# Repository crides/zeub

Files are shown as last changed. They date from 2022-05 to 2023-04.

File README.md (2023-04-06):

# Zeub

zeub is meant to be a pixel clock and a IoT hub. The name comes from a smooshed version of zeit (German for time) and hub.

It currently has:
- a 8x8 RGB LED matrix and a 32x8 white LED matrix
- 2 2-channel LED strip controllers (for controlling LED strips with warm and cool white lights in my room)
- a 128x64 OLED screen
- a TMP117 precision temperature sensor
- 2 front facing speakers, using 2 MAX98357 DACs
- a DS3212 battery backed RTC
- a EVQWGD001 rotary encoder, and a 5-way joystick
- a nRF52840 microcontroller, which supports USB, BLE and 802.15.4 (ZigBee etc.) protocols

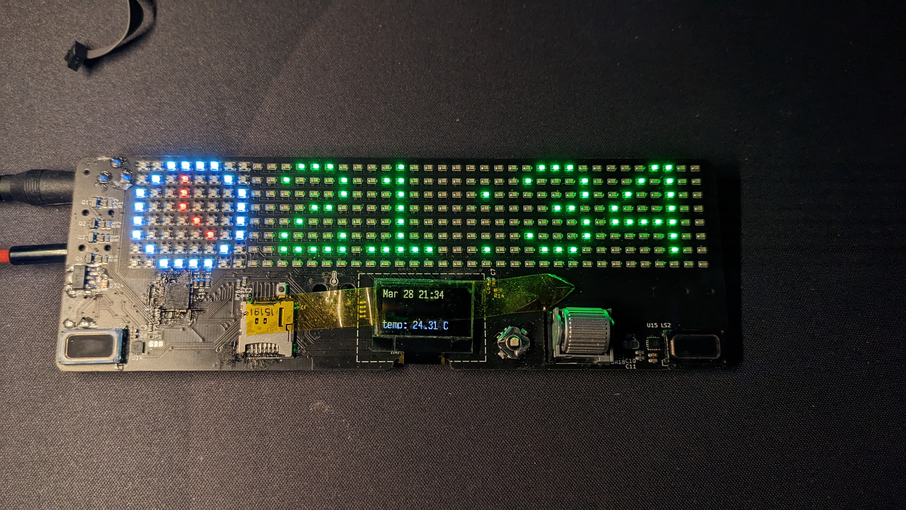
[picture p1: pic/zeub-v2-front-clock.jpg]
Version 2 assembled displaying a clock icon and time (the right side is green because uh.. I messed up the PCBA parts assignment): 

The current firmware fetches the current time (once; supports connection at 2 times for drift correction) from a CTS (Current Time Service) from a BLE connection. This is currently done using my phone through the nRF Connect app. The time is then displayed on both the LED matrix (along with a clock icon), and the OLED along with the date and current temperature. It also sets the brightness of one LED strip using a preconfigured (but can be reconfigured through BLE) schedule. The other LED strip (which is actually my desk light) is controlled by the scroll wheel. It also streams audio from the USB to the speakers, for testing of the audio interface.

The hub part of the project still doesn't really exist yet, as I haven't had time to get to it.

Version 1 has basically the same features, but also included 2 microphones for testing. However the LED matrix did not work properly as I used 2 LED matrix controllers together in the same matrix.

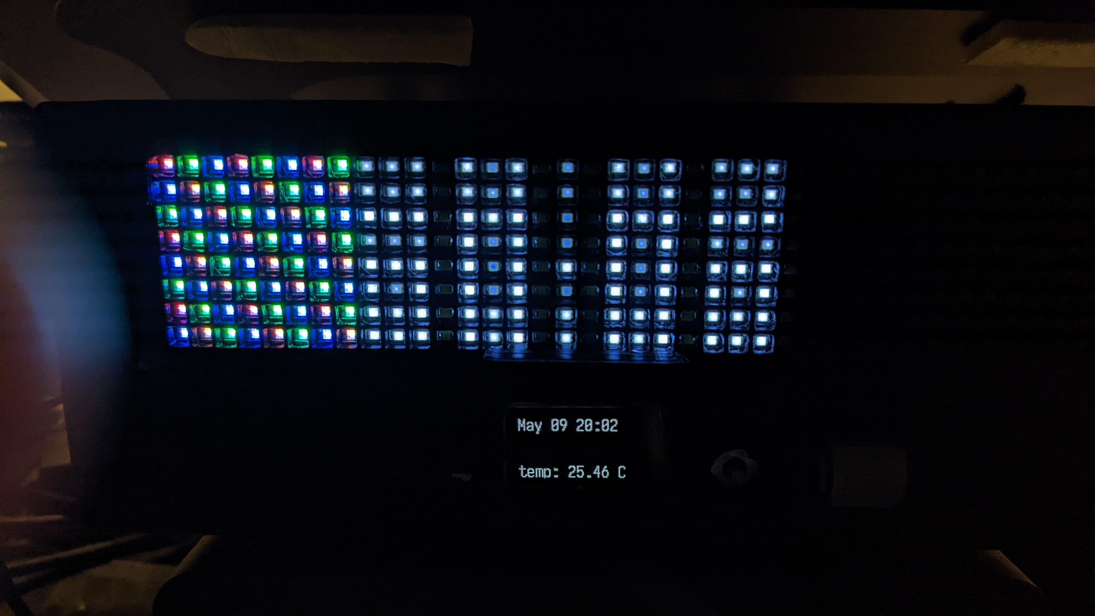
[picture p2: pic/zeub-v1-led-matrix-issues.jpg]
LED matrix issues


The LED strips were also connected through a TRRS cable but without an actual connector, as I flipped the control polarity of the LED strips (they are common anode instead of common cathode).

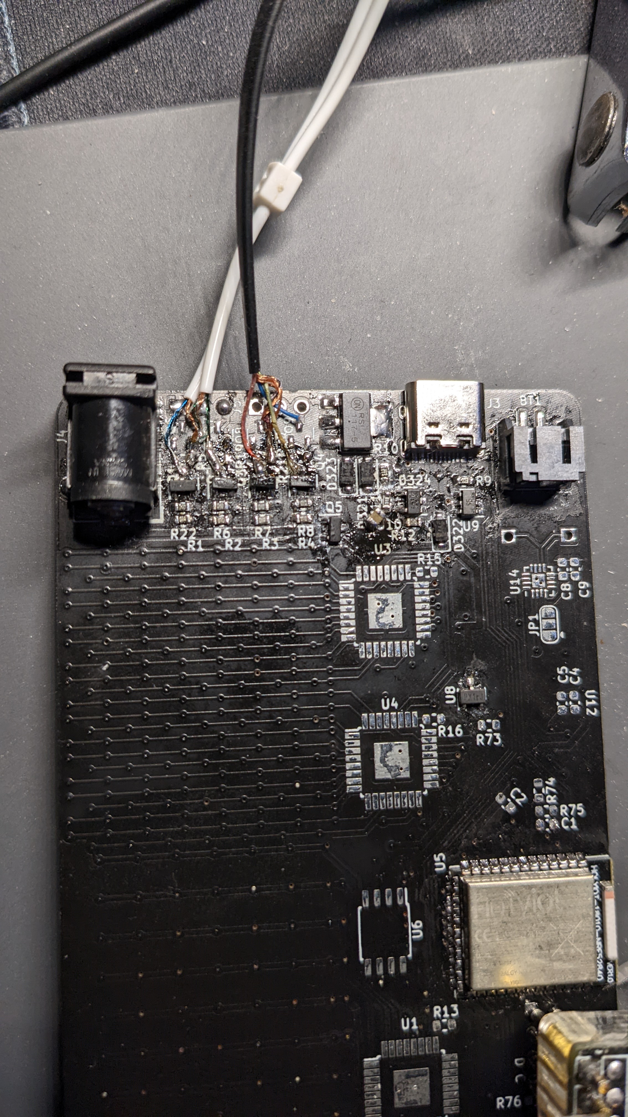
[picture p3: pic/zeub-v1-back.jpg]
V1 backside


Case iterations for v1 (the cone in the back is for better airflow to the temperature sensor, for more accurate reading of the environment):

V1 front cases

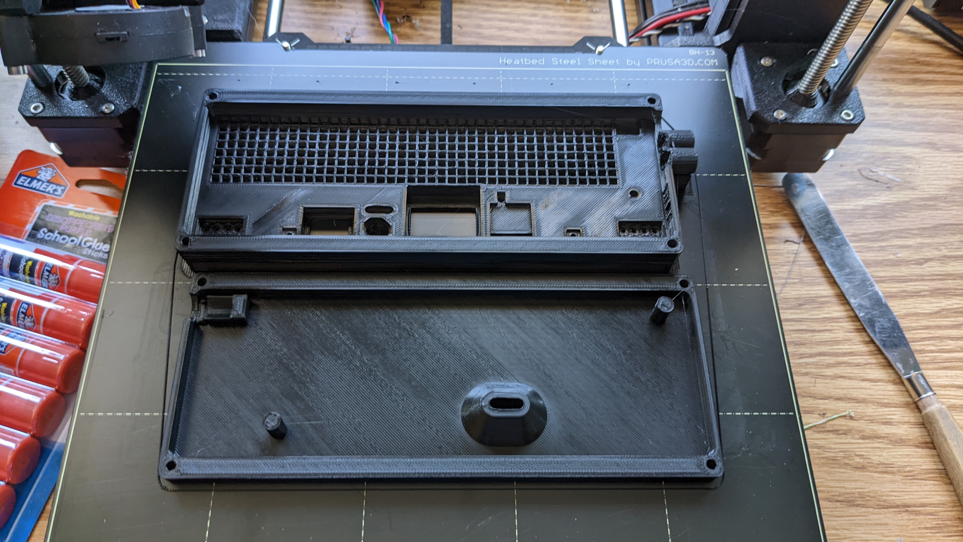
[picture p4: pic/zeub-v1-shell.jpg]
V1 front and back cases


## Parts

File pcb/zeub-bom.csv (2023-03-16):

Comment | Footprint | Designator | LCSC Part #
0.1uF | C_0603_1608Metric | C3,C20,C5,C6,C13,C14,C8,C10
100 | R_0603_1608Metric | R1,R2,R3,R4
100k | R_0603_1608Metric | R5,R6,R7,R8,R22,R73,R74,R75,R17,R18
10k | R_0603_1608Metric | R12,R14,R16
10uF | C_0603_1608Metric | C9,C11
1k | R_0603_1608Metric | R11
1uF | C_0603_1608Metric | C4,C15,C19,C2,C7,C12,C17,C18
2.2k | R_0603_1608Metric | R76,R77
2.2uF | C_0603_1608Metric | C16
390k | R_0603_1608Metric | R13
4.7uF | C_0603_1608Metric | C1
5.1k | R_0603_1608Metric | R9,R10
AO3400A | SOT-23 | Q1,Q2,Q3,Q4,Q5
AudioJack4 | Jack_3.5mm_PJ320D_Horizontal | J2,J5,J6
Barrel_Jack_Switch | BarrelJack_CUI_PJ-102AH_Horizontal | J4
Battery_Cell | JST_PH_S2B-PH-SM4-TB_1x02-1MP_P2.00mm_Horizontal | BT1
DS3231MZ | SOIC-8_3.9x4.9mm_P1.27mm | U3
D_Schottky | D_SOD-123 | D321,D322,D323
IS31FL3741 | QFN-60-1EP_7x7mm_P0.4mm_EP5.4x5.4mm_ThermalVias | U1,U2
LED | D_0805_2012Metric | D324
LED_BGRA | LED_ASMB-KTF0-0A306 | D257,D258,D259,D260,D261,D262,D263,D264,D265,D266,D267,D268,D269,D270,D271,D272,D273,D274,D275,D276,D277,D278,D279,D280,D281,D282,D283,D284,D285,D286,D287,D288,D289,D290,D291,D292,D293,D294,D295,D296,D297,D298,D299,D300,D301,D302,D303,D304,D305,D306,D307,D308,D309,D310,D311,D312,D313,D314,D315,D316,D317,D318,D319,D320
LTC4054ES5-4.2 | TSOT-23-5 | U10
MAX98357A | QFN-16-1EP_3x3mm_P0.5mm_EP1.45x1.45mm | U14,U15
Micro_SD_Card_Det | molex-503182-1852 | J7
OLED-128O064D | OLED-128O064D | DS1
RotaryEncoder_Switch | EVQWGD001 | SW2
SKRHA | SKRHA-boss | SW1
SRV05-4 | SOT-23-6 | U9
SW_Push | SW_SPST_B3U-1000P | SW3
SolderJumper_2_Open | SolderJumper-2_P1.3mm_Open_TrianglePad1.0x1.5mm | JP3,JP4
SolderJumper_3_Open | SolderJumper-3_P1.3mm_Open_RoundedPad1.0x1.5mm | JP1,JP2
Speaker | CMS1609 | LS1,LS2
TLV1117-50 | SOT-223 | U7
TMP117 | WSON-6-1EP_2x2mm_P0.65mm_EP1x1.6mm | U11
USB_C_Receptacle_USB2.0 | USB_C_Receptacle_HRO_TYPE-C-31-M-12 | J3
W25Q128JVS | SOIC-8_5.23x5.23mm_P1.27mm | U6
XC6206PxxxMR | SOT-23-3 | U8
holyiot-18010-no-underside | holyiot-18010-no-underside | U5
jlink | PinHeader_2x05_P1.27mm_Vertical_SMD | J1
white | D_0603_1608Metric | D1,D2,D3,D4,D5,D6,D7,D8,D9,D10,D11,D12,D13,D14,D15,D16,D17,D18,D19,D20,D21,D22,D23,D24,D25,D26,D27,D28,D29,D30,D31,D32,D33,D34,D35,D36,D37,D38,D39,D40,D41,D42,D43,D44,D45,D46,D47,D48,D49,D50,D51,D52,D53,D54,D55,D56,D57,D58,D59,D60,D61,D62,D63,D64,D65,D66,D67,D68,D69,D70,D71,D72,D73,D74,D75,D76,D77,D78,D79,D80,D81,D82,D83,D84,D85,D86,D87,D88,D89,D90,D91,D92,D93,D94,D95,D96,D97,D98,D99,D100,D101,D102,D103,D104,D105,D106,D107,D108,D109,D110,D111,D112,D113,D114,D115,D116,D117,D118,D119,D120,D121,D122,D123,D124,D125,D126,D127,D128,D129,D130,D131,D132,D133,D134,D135,D136,D137,D138,D139,D140,D141,D142,D143,D144,D145,D146,D147,D148,D149,D150,D151,D152,D153,D154,D155,D156,D157,D158,D159,D160,D161,D162,D163,D164,D165,D166,D167,D168,D169,D170,D171,D172,D173,D174,D175,D176,D177,D178,D179,D180,D181,D182,D183,D184,D185,D186,D187,D188,D189,D190,D191,D192,D193,D194,D195,D196,D197,D198,D199,D200,D201,D202,D203,D204,D205,D206,D207,D208,D209,D210,D211,D212,D213,D214,D215,D216,D217,D218,D219,D220,D221,D222,D223,D224,D225,D226,D227,D228,D229,D230,D231,D232,D233,D234,D235,D236,D237,D238,D239,D240,D241,D242,D243,D244,D245,D246,D247,D248,D249,D250,D251,D252,D253,D254,D255,D256

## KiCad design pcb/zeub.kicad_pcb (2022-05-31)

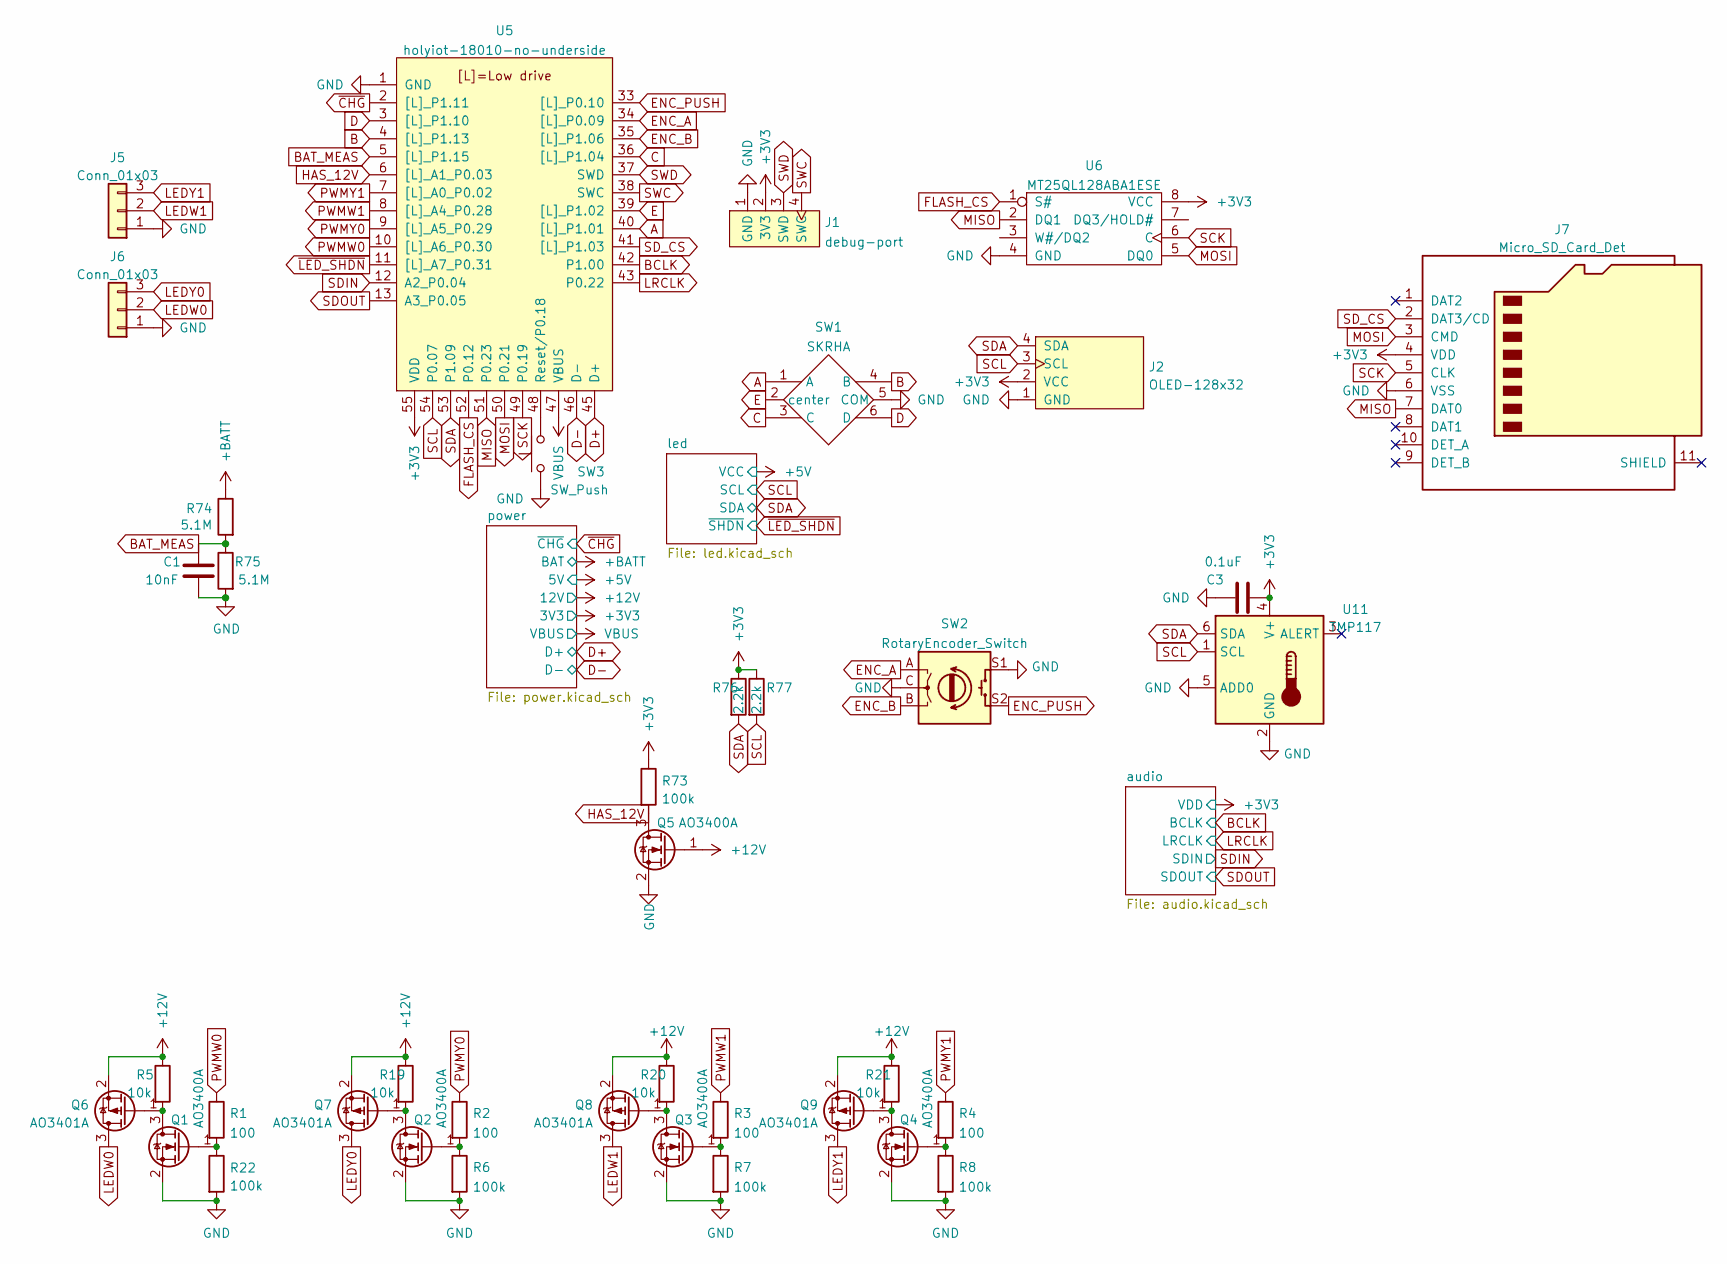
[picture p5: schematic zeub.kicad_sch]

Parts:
C1: 10nF; C_0603_1608Metric
C3: 0.1uF; C_0603_1608Metric
J1: debug-port; debug-port-single-side
J2: OLED-128x32; OLED-128x64
J5, J6: Conn_01x03; PinHeader_1x03_P2.54mm_Vertical
J7: Micro_SD_Card_Det; molex-503182-1852
Q1, Q2, Q3, Q4, Q5: AO3400A; SOT-23
Q6, Q7, Q8, Q9: AO3401A; SOT-23
R1, R2, R3, R4: 100; R_0603_1608Metric
R5, R19, R20, R21: 10k; R_0603_1608Metric
R6, R7, R8, R22, R73: 100k; R_0603_1608Metric
R74, R75: 5.1M; R_0603_1608Metric
R76, R77: 2.2k; R_0603_1608Metric
SW1: SKRHA; SKRHA-boss
SW2: RotaryEncoder_Switch; EVQWGD001
SW3: SW_Push; SW_SPST_B3U-1000P
U5: holyiot-18010-no-underside
U6: MT25QL128ABA1ESE; SOIC-8_5.23x5.23mm_P1.27mm
U11: TMP117; WSON-6-1EP_2x2mm_P0.65mm_EP1x1.6mm

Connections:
+3V3: C3.2, J1.2 (3V3), J2.2 (VCC), J7.4 (VDD), R73.1, R76.1, R77.1, U5.55 (VDD), U6.8 (VCC), U11.4 (V+); also elsewhere on the board
+12V: Q5.1 (G), Q6.2 (S), Q7.2 (S), Q8.2 (S), Q9.2 (S), R5.1, R19.1, R20.1, R21.1; also elsewhere on the board
+BATT: R74.1; also elsewhere on the board
A: SW1.1 (A), U5.40 ([L]_P1.01)
B: SW1.4 (B), U5.4 ([L]_P1.13)
BAT_MEAS: C1.1, R74.2, R75.1, U5.5 ([L]_P1.15)
BCLK: U5.42 (P1.00); also elsewhere on the board
C: SW1.3 (C), U5.36 ([L]_P1.04)
D: SW1.6 (D), U5.3 ([L]_P1.10)
D+: U5.45 (D+); also elsewhere on the board
D-: U5.46 (D-); also elsewhere on the board
E: SW1.2 (center), U5.39 ([L]_P1.02)
ENC_A: SW2.A, U5.34 ([L]_P0.09)
ENC_B: SW2.B, U5.35 ([L]_P1.06)
ENC_PUSH: SW2.S2, U5.33 ([L]_P0.10)
FLASH_CS: U5.52 (P0.12), U6.1 (S#)
GND: C1.2, C3.1, J1.1 (GND), J2.1 (GND), J5.1, J6.1, J7.6 (VSS), Q1.2 (S), Q2.2 (S), Q3.2 (S), Q4.2 (S), Q5.2 (S), R6.2, R7.2, R8.2, R22.2, R75.2, SW1.5 (COM), SW2.C, SW2.S1, SW3.1, U5.1 (GND), U5.32 (GND), U5.44 (GND), U6.4 (GND), U11.2 (GND), U11.5 (ADD0), U11.7 (GND); also elsewhere on the board
HAS_12V: Q5.3 (D), R73.2, U5.6 ([L]_A1_P0.03)
LEDW0: J6.2, Q6.3 (D)
LEDW1: J5.2, Q8.3 (D)
LEDY0: J6.3, Q7.3 (D)
LEDY1: J5.3, Q9.3 (D)
LRCLK: U5.43 (P0.22); also elsewhere on the board
MISO: J7.7 (DAT0), U5.51 (P0.23), U6.2 (DQ1)
MOSI: J7.3 (CMD), U5.50 (P0.21), U6.5 (DQ0)
unnamed: Q1.1 (G), R1.2, R22.1
unnamed: Q1.3 (D), Q6.1 (G), R5.2
unnamed: Q2.1 (G), R2.2, R6.1
unnamed: Q2.3 (D), Q7.1 (G), R19.2
unnamed: Q3.1 (G), R3.2, R7.1
unnamed: Q3.3 (D), Q8.1 (G), R20.2
unnamed: Q4.1 (G), R4.2, R8.1
unnamed: Q4.3 (D), Q9.1 (G), R21.2
unnamed: SW3.2, U5.48 (Reset/P0.18)
PWMW0: R1.1, U5.10 ([L]_A6_P0.30)
PWMW1: R3.1, U5.8 ([L]_A4_P0.28)
PWMY0: R2.1, U5.9 ([L]_A5_P0.29)
PWMY1: R4.1, U5.7 ([L]_A0_P0.02)
SCK: J7.5 (CLK), U5.49 (P0.19), U6.6 (C)
SCL: J2.3 (SCL), R77.2, U5.54 (P0.07), U11.1 (SCL); also elsewhere on the board
SDA: J2.4 (SDA), R76.2, U5.53 (P1.09), U11.6 (SDA); also elsewhere on the board
SDIN: U5.12 (A2_P0.04); also elsewhere on the board
SDOUT: U5.13 (A3_P0.05); also elsewhere on the board
SD_CS: J7.2 (DAT3/CD), U5.41 ([L]_P1.03)
SWC: J1.4 (SWC), U5.38 (SWC)
SWD: J1.3 (SWD), U5.37 (SWD)
VBUS: U5.47 (VBUS); also elsewhere on the board
~CHG: U5.2 ([L]_P1.11); also elsewhere on the board
~LED_SHDN: U5.11 ([L]_A7_P0.31); also elsewhere on the board

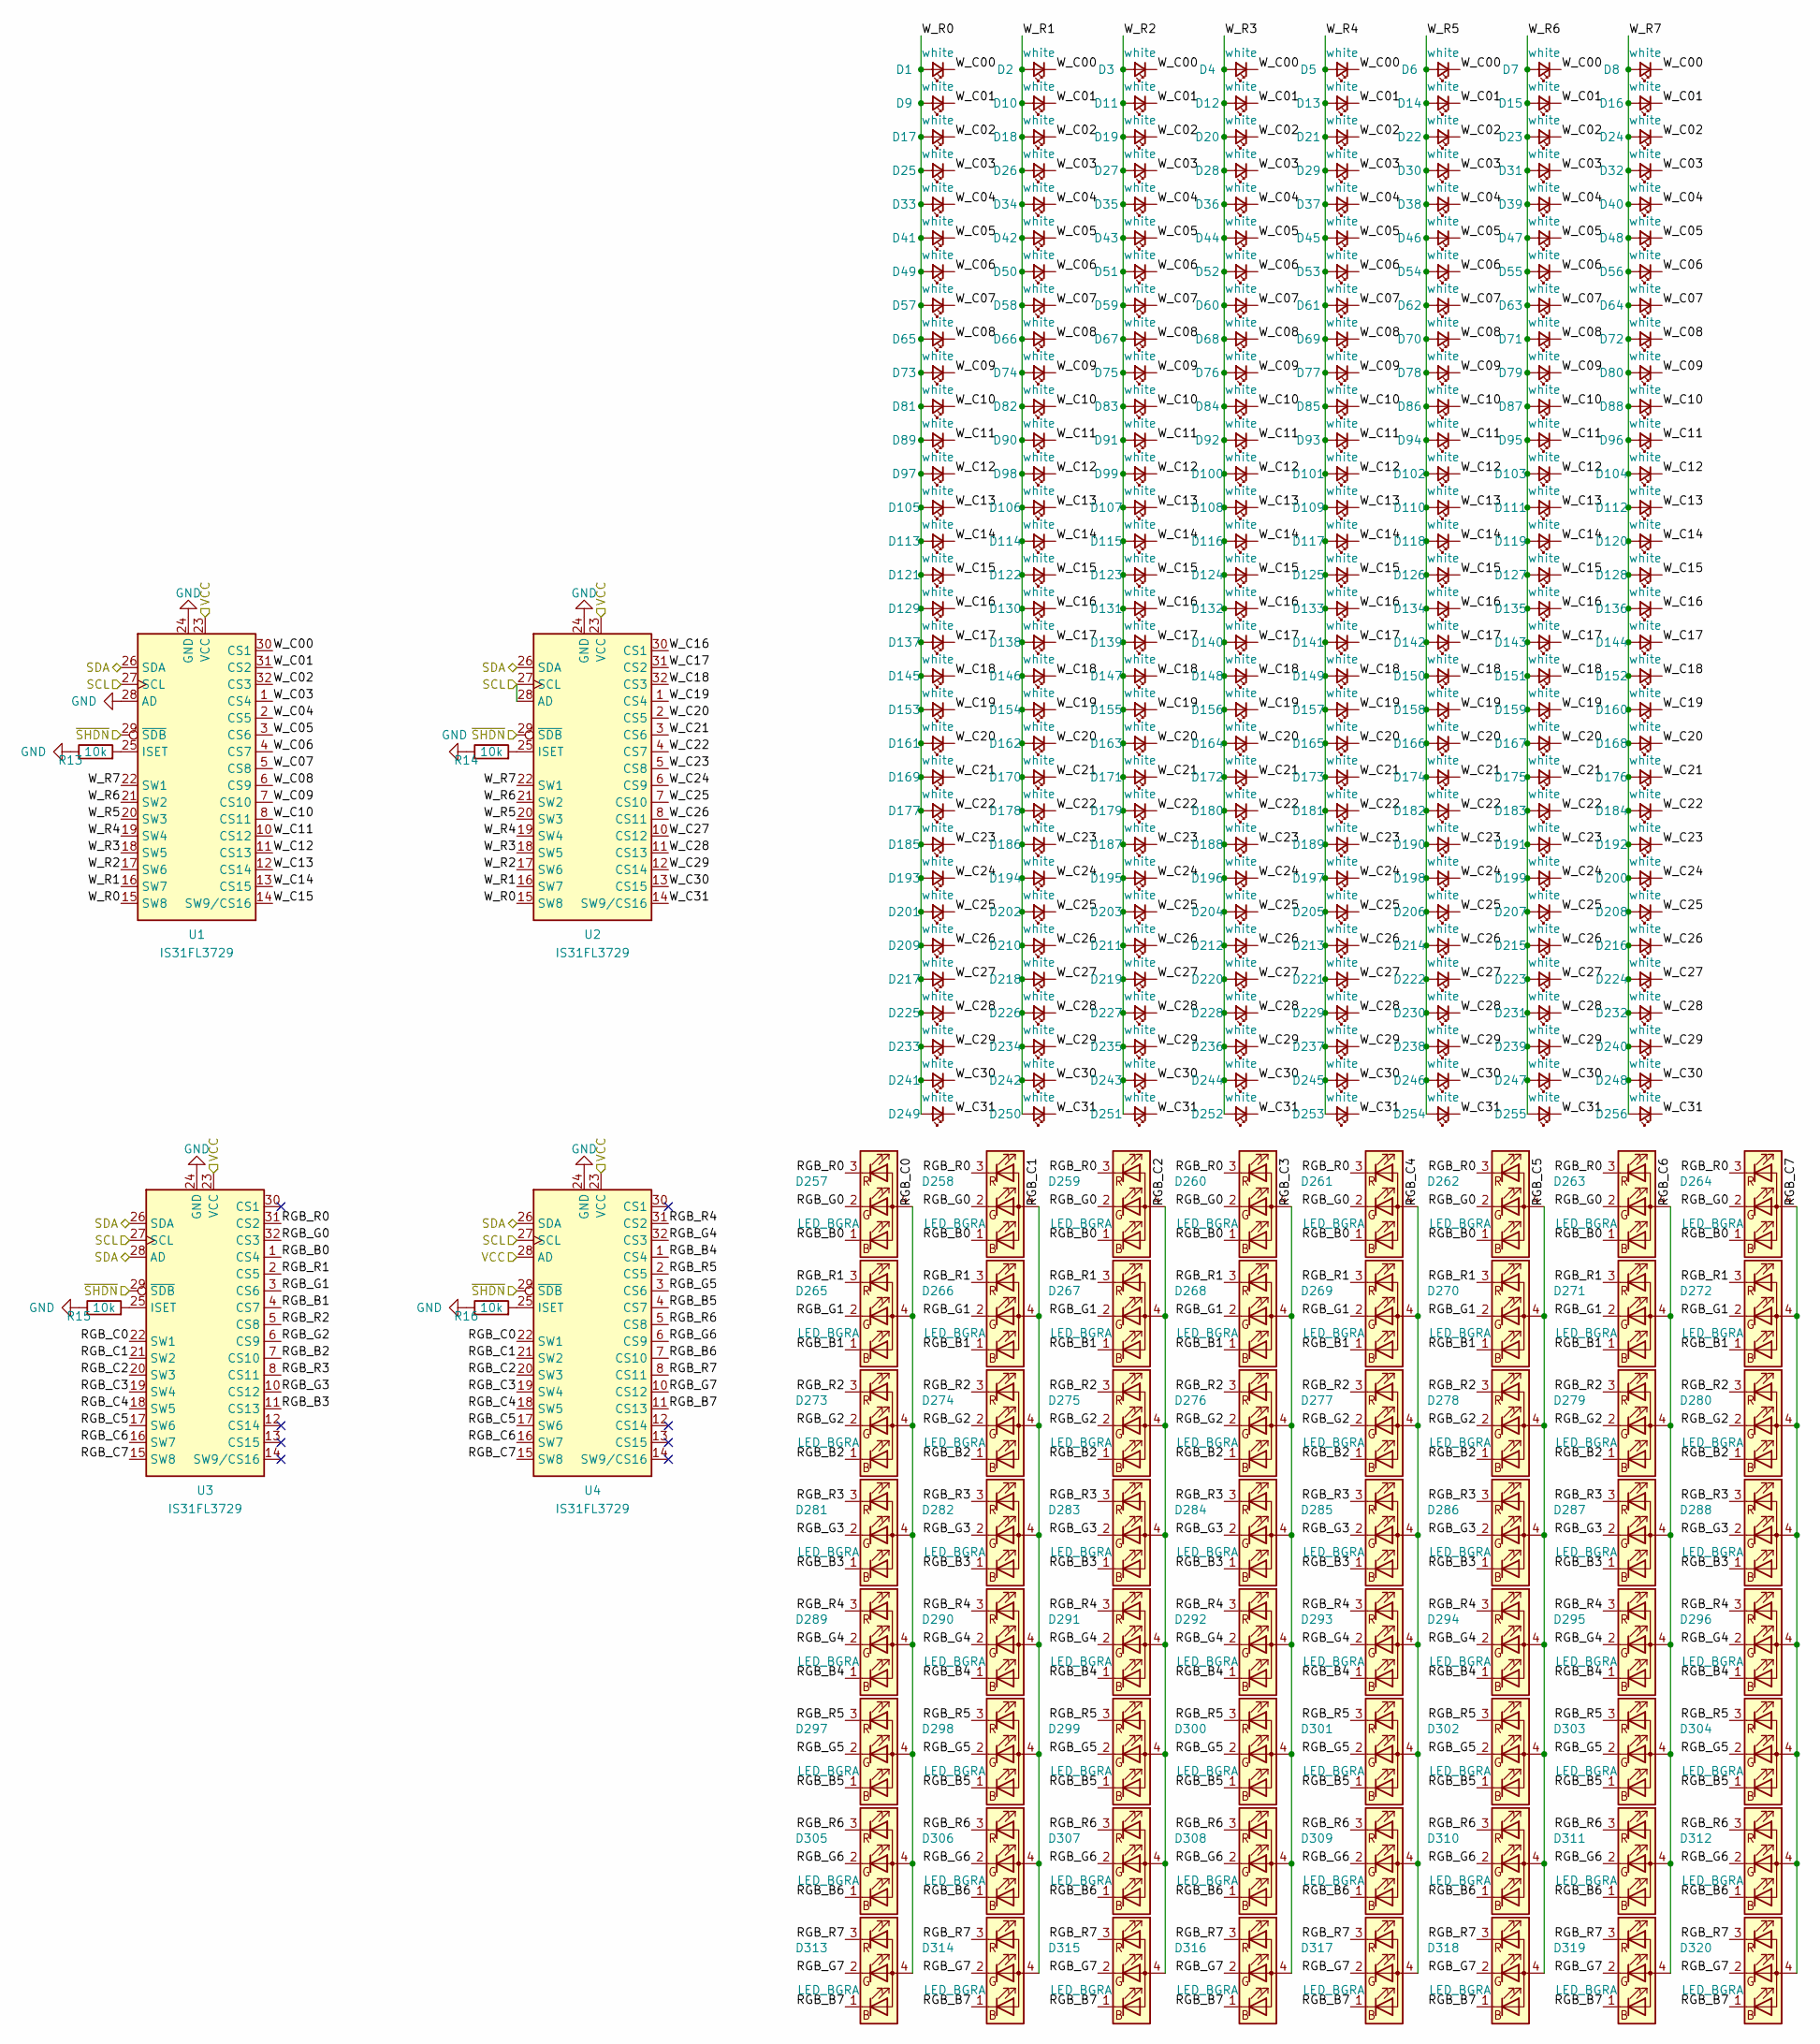
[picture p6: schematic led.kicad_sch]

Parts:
D1, D2, D3, D4, D5, D6, D7, D8, D9, D10, D11, D12, D13, D14, D15, D16, D17, D18, D19, D20, D21, D22, D23, D24, D25, D26, D27, D28, D29, D30, D31, D32, D33, D34, D35, D36, D37, D38, D39, D40, D41, D42, D43, D44, D45, D46, D47, D48, D49, D50, D51, D52, D53, D54, D55, D56, D57, D58, D59, D60, D61, D62, D63, D64, D65, D66, D67, D68, D69, D70, D71, D72, D73, D74, D75, D76, D77, D78, D79, D80, D81, D82, D83, D84, D85, D86, D87, D88, D89, D90, D91, D92, D93, D94, D95, D96, D97, D98, D99, D100, D101, D102, D103, D104, D105, D106, D107, D108, D109, D110, D111, D112, D113, D114, D115, D116, D117, D118, D119, D120, D121, D122, D123, D124, D125, D126, D127, D128, D129, D130, D131, D132, D133, D134, D135, D136, D137, D138, D139, D140, D141, D142, D143, D144, D145, D146, D147, D148, D149, D150, D151, D152, D153, D154, D155, D156, D157, D158, D159, D160, D161, D162, D163, D164, D165, D166, D167, D168, D169, D170, D171, D172, D173, D174, D175, D176, D177, D178, D179, D180, D181, D182, D183, D184, D185, D186, D187, D188, D189, D190, D191, D192, D193, D194, D195, D196, D197, D198, D199, D200, D201, D202, D203, D204, D205, D206, D207, D208, D209, D210, D211, D212, D213, D214, D215, D216, D217, D218, D219, D220, D221, D222, D223, D224, D225, D226, D227, D228, D229, D230, D231, D232, D233, D234, D235, D236, D237, D238, D239, D240, D241, D242, D243, D244, D245, D246, D247, D248, D249, D250, D251, D252, D253, D254, D255, D256: white; D_0603_1608Metric
D257, D258, D259, D260, D261, D262, D263, D264, D265, D266, D267, D268, D269, D270, D271, D272, D273, D274, D275, D276, D277, D278, D279, D280, D281, D282, D283, D284, D285, D286, D287, D288, D289, D290, D291, D292, D293, D294, D295, D296, D297, D298, D299, D300, D301, D302, D303, D304, D305, D306, D307, D308, D309, D310, D311, D312, D313, D314, D315, D316, D317, D318, D319, D320: LED_BGRA; LED_ASMB-KTF0-0A306
R13, R14, R15, R16: 10k; R_0603_1608Metric
U1, U2, U3, U4: IS31FL3729; eTQFP-32_7x7mm_P0.8mm

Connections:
+5V: U1.23 (VCC), U2.23 (VCC), U3.23 (VCC), U4.23 (VCC), U4.28 (AD); also elsewhere on the board
/led/RGB_B0: D257.1 (BK), D258.1 (BK), D259.1 (BK), D260.1 (BK), D261.1 (BK), D262.1 (BK), D263.1 (BK), D264.1 (BK), U3.1 (CS4)
/led/RGB_B1: D265.1 (BK), D266.1 (BK), D267.1 (BK), D268.1 (BK), D269.1 (BK), D270.1 (BK), D271.1 (BK), D272.1 (BK), U3.4 (CS7)
/led/RGB_B2: D273.1 (BK), D274.1 (BK), D275.1 (BK), D276.1 (BK), D277.1 (BK), D278.1 (BK), D279.1 (BK), D280.1 (BK), U3.7 (CS10)
/led/RGB_B3: D281.1 (BK), D282.1 (BK), D283.1 (BK), D284.1 (BK), D285.1 (BK), D286.1 (BK), D287.1 (BK), D288.1 (BK), U3.11 (CS13)
/led/RGB_B4: D289.1 (BK), D290.1 (BK), D291.1 (BK), D292.1 (BK), D293.1 (BK), D294.1 (BK), D295.1 (BK), D296.1 (BK), U4.1 (CS4)
/led/RGB_B5: D297.1 (BK), D298.1 (BK), D299.1 (BK), D300.1 (BK), D301.1 (BK), D302.1 (BK), D303.1 (BK), D304.1 (BK), U4.4 (CS7)
/led/RGB_B6: D305.1 (BK), D306.1 (BK), D307.1 (BK), D308.1 (BK), D309.1 (BK), D310.1 (BK), D311.1 (BK), D312.1 (BK), U4.7 (CS10)
/led/RGB_B7: D313.1 (BK), D314.1 (BK), D315.1 (BK), D316.1 (BK), D317.1 (BK), D318.1 (BK), D319.1 (BK), D320.1 (BK), U4.11 (CS13)
/led/RGB_C0: D257.4 (A), D265.4 (A), D273.4 (A), D281.4 (A), D289.4 (A), D297.4 (A), D305.4 (A), D313.4 (A), U3.22 (SW1), U4.22 (SW1)
/led/RGB_C1: D258.4 (A), D266.4 (A), D274.4 (A), D282.4 (A), D290.4 (A), D298.4 (A), D306.4 (A), D314.4 (A), U3.21 (SW2), U4.21 (SW2)
/led/RGB_C2: D259.4 (A), D267.4 (A), D275.4 (A), D283.4 (A), D291.4 (A), D299.4 (A), D307.4 (A), D315.4 (A), U3.20 (SW3), U4.20 (SW3)
/led/RGB_C3: D260.4 (A), D268.4 (A), D276.4 (A), D284.4 (A), D292.4 (A), D300.4 (A), D308.4 (A), D316.4 (A), U3.19 (SW4), U4.19 (SW4)
/led/RGB_C4: D261.4 (A), D269.4 (A), D277.4 (A), D285.4 (A), D293.4 (A), D301.4 (A), D309.4 (A), D317.4 (A), U3.18 (SW5), U4.18 (SW5)
/led/RGB_C5: D262.4 (A), D270.4 (A), D278.4 (A), D286.4 (A), D294.4 (A), D302.4 (A), D310.4 (A), D318.4 (A), U3.17 (SW6), U4.17 (SW6)
/led/RGB_C6: D263.4 (A), D271.4 (A), D279.4 (A), D287.4 (A), D295.4 (A), D303.4 (A), D311.4 (A), D319.4 (A), U3.16 (SW7), U4.16 (SW7)
/led/RGB_C7: D264.4 (A), D272.4 (A), D280.4 (A), D288.4 (A), D296.4 (A), D304.4 (A), D312.4 (A), D320.4 (A), U3.15 (SW8), U4.15 (SW8)
/led/RGB_G0: D257.2 (GK), D258.2 (GK), D259.2 (GK), D260.2 (GK), D261.2 (GK), D262.2 (GK), D263.2 (GK), D264.2 (GK), U3.32 (CS3)
/led/RGB_G1: D265.2 (GK), D266.2 (GK), D267.2 (GK), D268.2 (GK), D269.2 (GK), D270.2 (GK), D271.2 (GK), D272.2 (GK), U3.3 (CS6)
/led/RGB_G2: D273.2 (GK), D274.2 (GK), D275.2 (GK), D276.2 (GK), D277.2 (GK), D278.2 (GK), D279.2 (GK), D280.2 (GK), U3.6 (CS9)
/led/RGB_G3: D281.2 (GK), D282.2 (GK), D283.2 (GK), D284.2 (GK), D285.2 (GK), D286.2 (GK), D287.2 (GK), D288.2 (GK), U3.10 (CS12)
/led/RGB_G4: D289.2 (GK), D290.2 (GK), D291.2 (GK), D292.2 (GK), D293.2 (GK), D294.2 (GK), D295.2 (GK), D296.2 (GK), U4.32 (CS3)
/led/RGB_G5: D297.2 (GK), D298.2 (GK), D299.2 (GK), D300.2 (GK), D301.2 (GK), D302.2 (GK), D303.2 (GK), D304.2 (GK), U4.3 (CS6)
/led/RGB_G6: D305.2 (GK), D306.2 (GK), D307.2 (GK), D308.2 (GK), D309.2 (GK), D310.2 (GK), D311.2 (GK), D312.2 (GK), U4.6 (CS9)
/led/RGB_G7: D313.2 (GK), D314.2 (GK), D315.2 (GK), D316.2 (GK), D317.2 (GK), D318.2 (GK), D319.2 (GK), D320.2 (GK), U4.10 (CS12)
/led/RGB_R0: D257.3 (RK), D258.3 (RK), D259.3 (RK), D260.3 (RK), D261.3 (RK), D262.3 (RK), D263.3 (RK), D264.3 (RK), U3.31 (CS2)
/led/RGB_R1: D265.3 (RK), D266.3 (RK), D267.3 (RK), D268.3 (RK), D269.3 (RK), D270.3 (RK), D271.3 (RK), D272.3 (RK), U3.2 (CS5)
/led/RGB_R2: D273.3 (RK), D274.3 (RK), D275.3 (RK), D276.3 (RK), D277.3 (RK), D278.3 (RK), D279.3 (RK), D280.3 (RK), U3.5 (CS8)
/led/RGB_R3: D281.3 (RK), D282.3 (RK), D283.3 (RK), D284.3 (RK), D285.3 (RK), D286.3 (RK), D287.3 (RK), D288.3 (RK), U3.8 (CS11)
/led/RGB_R4: D289.3 (RK), D290.3 (RK), D291.3 (RK), D292.3 (RK), D293.3 (RK), D294.3 (RK), D295.3 (RK), D296.3 (RK), U4.31 (CS2)
/led/RGB_R5: D297.3 (RK), D298.3 (RK), D299.3 (RK), D300.3 (RK), D301.3 (RK), D302.3 (RK), D303.3 (RK), D304.3 (RK), U4.2 (CS5)
/led/RGB_R6: D305.3 (RK), D306.3 (RK), D307.3 (RK), D308.3 (RK), D309.3 (RK), D310.3 (RK), D311.3 (RK), D312.3 (RK), U4.5 (CS8)
/led/RGB_R7: D313.3 (RK), D314.3 (RK), D315.3 (RK), D316.3 (RK), D317.3 (RK), D318.3 (RK), D319.3 (RK), D320.3 (RK), U4.8 (CS11)
/led/W_C00: D1.1 (K), D2.1 (K), D3.1 (K), D4.1 (K), D5.1 (K), D6.1 (K), D7.1 (K), D8.1 (K), U1.30 (CS1)
/led/W_C01: D9.1 (K), D10.1 (K), D11.1 (K), D12.1 (K), D13.1 (K), D14.1 (K), D15.1 (K), D16.1 (K), U1.31 (CS2)
/led/W_C02: D17.1 (K), D18.1 (K), D19.1 (K), D20.1 (K), D21.1 (K), D22.1 (K), D23.1 (K), D24.1 (K), U1.32 (CS3)
/led/W_C03: D25.1 (K), D26.1 (K), D27.1 (K), D28.1 (K), D29.1 (K), D30.1 (K), D31.1 (K), D32.1 (K), U1.1 (CS4)
/led/W_C04: D33.1 (K), D34.1 (K), D35.1 (K), D36.1 (K), D37.1 (K), D38.1 (K), D39.1 (K), D40.1 (K), U1.2 (CS5)
/led/W_C05: D41.1 (K), D42.1 (K), D43.1 (K), D44.1 (K), D45.1 (K), D46.1 (K), D47.1 (K), D48.1 (K), U1.3 (CS6)
/led/W_C06: D49.1 (K), D50.1 (K), D51.1 (K), D52.1 (K), D53.1 (K), D54.1 (K), D55.1 (K), D56.1 (K), U1.4 (CS7)
/led/W_C07: D57.1 (K), D58.1 (K), D59.1 (K), D60.1 (K), D61.1 (K), D62.1 (K), D63.1 (K), D64.1 (K), U1.5 (CS8)
/led/W_C08: D65.1 (K), D66.1 (K), D67.1 (K), D68.1 (K), D69.1 (K), D70.1 (K), D71.1 (K), D72.1 (K), U1.6 (CS9)
/led/W_C09: D73.1 (K), D74.1 (K), D75.1 (K), D76.1 (K), D77.1 (K), D78.1 (K), D79.1 (K), D80.1 (K), U1.7 (CS10)
/led/W_C10: D81.1 (K), D82.1 (K), D83.1 (K), D84.1 (K), D85.1 (K), D86.1 (K), D87.1 (K), D88.1 (K), U1.8 (CS11)
/led/W_C11: D89.1 (K), D90.1 (K), D91.1 (K), D92.1 (K), D93.1 (K), D94.1 (K), D95.1 (K), D96.1 (K), U1.10 (CS12)
/led/W_C12: D97.1 (K), D98.1 (K), D99.1 (K), D100.1 (K), D101.1 (K), D102.1 (K), D103.1 (K), D104.1 (K), U1.11 (CS13)
/led/W_C13: D105.1 (K), D106.1 (K), D107.1 (K), D108.1 (K), D109.1 (K), D110.1 (K), D111.1 (K), D112.1 (K), U1.12 (CS14)
/led/W_C14: D113.1 (K), D114.1 (K), D115.1 (K), D116.1 (K), D117.1 (K), D118.1 (K), D119.1 (K), D120.1 (K), U1.13 (CS15)
/led/W_C15: D121.1 (K), D122.1 (K), D123.1 (K), D124.1 (K), D125.1 (K), D126.1 (K), D127.1 (K), D128.1 (K), U1.14 (SW9/CS16)
/led/W_C16: D129.1 (K), D130.1 (K), D131.1 (K), D132.1 (K), D133.1 (K), D134.1 (K), D135.1 (K), D136.1 (K), U2.30 (CS1)
/led/W_C17: D137.1 (K), D138.1 (K), D139.1 (K), D140.1 (K), D141.1 (K), D142.1 (K), D143.1 (K), D144.1 (K), U2.31 (CS2)
/led/W_C18: D145.1 (K), D146.1 (K), D147.1 (K), D148.1 (K), D149.1 (K), D150.1 (K), D151.1 (K), D152.1 (K), U2.32 (CS3)
/led/W_C19: D153.1 (K), D154.1 (K), D155.1 (K), D156.1 (K), D157.1 (K), D158.1 (K), D159.1 (K), D160.1 (K), U2.1 (CS4)
/led/W_C20: D161.1 (K), D162.1 (K), D163.1 (K), D164.1 (K), D165.1 (K), D166.1 (K), D167.1 (K), D168.1 (K), U2.2 (CS5)
/led/W_C21: D169.1 (K), D170.1 (K), D171.1 (K), D172.1 (K), D173.1 (K), D174.1 (K), D175.1 (K), D176.1 (K), U2.3 (CS6)
/led/W_C22: D177.1 (K), D178.1 (K), D179.1 (K), D180.1 (K), D181.1 (K), D182.1 (K), D183.1 (K), D184.1 (K), U2.4 (CS7)
/led/W_C23: D185.1 (K), D186.1 (K), D187.1 (K), D188.1 (K), D189.1 (K), D190.1 (K), D191.1 (K), D192.1 (K), U2.5 (CS8)
/led/W_C24: D193.1 (K), D194.1 (K), D195.1 (K), D196.1 (K), D197.1 (K), D198.1 (K), D199.1 (K), D200.1 (K), U2.6 (CS9)
/led/W_C25: D201.1 (K), D202.1 (K), D203.1 (K), D204.1 (K), D205.1 (K), D206.1 (K), D207.1 (K), D208.1 (K), U2.7 (CS10)
/led/W_C26: D209.1 (K), D210.1 (K), D211.1 (K), D212.1 (K), D213.1 (K), D214.1 (K), D215.1 (K), D216.1 (K), U2.8 (CS11)
/led/W_C27: D217.1 (K), D218.1 (K), D219.1 (K), D220.1 (K), D221.1 (K), D222.1 (K), D223.1 (K), D224.1 (K), U2.10 (CS12)
/led/W_C28: D225.1 (K), D226.1 (K), D227.1 (K), D228.1 (K), D229.1 (K), D230.1 (K), D231.1 (K), D232.1 (K), U2.11 (CS13)
/led/W_C29: D233.1 (K), D234.1 (K), D235.1 (K), D236.1 (K), D237.1 (K), D238.1 (K), D239.1 (K), D240.1 (K), U2.12 (CS14)
/led/W_C30: D241.1 (K), D242.1 (K), D243.1 (K), D244.1 (K), D245.1 (K), D246.1 (K), D247.1 (K), D248.1 (K), U2.13 (CS15)
/led/W_C31: D249.1 (K), D250.1 (K), D251.1 (K), D252.1 (K), D253.1 (K), D254.1 (K), D255.1 (K), D256.1 (K), U2.14 (SW9/CS16)
/led/W_R0: D1.2 (A), D9.2 (A), D17.2 (A), D25.2 (A), D33.2 (A), D41.2 (A), D49.2 (A), D57.2 (A), D65.2 (A), D73.2 (A), D81.2 (A), D89.2 (A), D97.2 (A), D105.2 (A), D113.2 (A), D121.2 (A), D129.2 (A), D137.2 (A), D145.2 (A), D153.2 (A), D161.2 (A), D169.2 (A), D177.2 (A), D185.2 (A), D193.2 (A), D201.2 (A), D209.2 (A), D217.2 (A), D225.2 (A), D233.2 (A), D241.2 (A), D249.2 (A), U1.15 (SW8), U2.15 (SW8)
/led/W_R1: D2.2 (A), D10.2 (A), D18.2 (A), D26.2 (A), D34.2 (A), D42.2 (A), D50.2 (A), D58.2 (A), D66.2 (A), D74.2 (A), D82.2 (A), D90.2 (A), D98.2 (A), D106.2 (A), D114.2 (A), D122.2 (A), D130.2 (A), D138.2 (A), D146.2 (A), D154.2 (A), D162.2 (A), D170.2 (A), D178.2 (A), D186.2 (A), D194.2 (A), D202.2 (A), D210.2 (A), D218.2 (A), D226.2 (A), D234.2 (A), D242.2 (A), D250.2 (A), U1.16 (SW7), U2.16 (SW7)
/led/W_R2: D3.2 (A), D11.2 (A), D19.2 (A), D27.2 (A), D35.2 (A), D43.2 (A), D51.2 (A), D59.2 (A), D67.2 (A), D75.2 (A), D83.2 (A), D91.2 (A), D99.2 (A), D107.2 (A), D115.2 (A), D123.2 (A), D131.2 (A), D139.2 (A), D147.2 (A), D155.2 (A), D163.2 (A), D171.2 (A), D179.2 (A), D187.2 (A), D195.2 (A), D203.2 (A), D211.2 (A), D219.2 (A), D227.2 (A), D235.2 (A), D243.2 (A), D251.2 (A), U1.17 (SW6), U2.17 (SW6)
/led/W_R3: D4.2 (A), D12.2 (A), D20.2 (A), D28.2 (A), D36.2 (A), D44.2 (A), D52.2 (A), D60.2 (A), D68.2 (A), D76.2 (A), D84.2 (A), D92.2 (A), D100.2 (A), D108.2 (A), D116.2 (A), D124.2 (A), D132.2 (A), D140.2 (A), D148.2 (A), D156.2 (A), D164.2 (A), D172.2 (A), D180.2 (A), D188.2 (A), D196.2 (A), D204.2 (A), D212.2 (A), D220.2 (A), D228.2 (A), D236.2 (A), D244.2 (A), D252.2 (A), U1.18 (SW5), U2.18 (SW5)
/led/W_R4: D5.2 (A), D13.2 (A), D21.2 (A), D29.2 (A), D37.2 (A), D45.2 (A), D53.2 (A), D61.2 (A), D69.2 (A), D77.2 (A), D85.2 (A), D93.2 (A), D101.2 (A), D109.2 (A), D117.2 (A), D125.2 (A), D133.2 (A), D141.2 (A), D149.2 (A), D157.2 (A), D165.2 (A), D173.2 (A), D181.2 (A), D189.2 (A), D197.2 (A), D205.2 (A), D213.2 (A), D221.2 (A), D229.2 (A), D237.2 (A), D245.2 (A), D253.2 (A), U1.19 (SW4), U2.19 (SW4)
/led/W_R5: D6.2 (A), D14.2 (A), D22.2 (A), D30.2 (A), D38.2 (A), D46.2 (A), D54.2 (A), D62.2 (A), D70.2 (A), D78.2 (A), D86.2 (A), D94.2 (A), D102.2 (A), D110.2 (A), D118.2 (A), D126.2 (A), D134.2 (A), D142.2 (A), D150.2 (A), D158.2 (A), D166.2 (A), D174.2 (A), D182.2 (A), D190.2 (A), D198.2 (A), D206.2 (A), D214.2 (A), D222.2 (A), D230.2 (A), D238.2 (A), D246.2 (A), D254.2 (A), U1.20 (SW3), U2.20 (SW3)
/led/W_R6: D7.2 (A), D15.2 (A), D23.2 (A), D31.2 (A), D39.2 (A), D47.2 (A), D55.2 (A), D63.2 (A), D71.2 (A), D79.2 (A), D87.2 (A), D95.2 (A), D103.2 (A), D111.2 (A), D119.2 (A), D127.2 (A), D135.2 (A), D143.2 (A), D151.2 (A), D159.2 (A), D167.2 (A), D175.2 (A), D183.2 (A), D191.2 (A), D199.2 (A), D207.2 (A), D215.2 (A), D223.2 (A), D231.2 (A), D239.2 (A), D247.2 (A), D255.2 (A), U1.21 (SW2), U2.21 (SW2)
/led/W_R7: D8.2 (A), D16.2 (A), D24.2 (A), D32.2 (A), D40.2 (A), D48.2 (A), D56.2 (A), D64.2 (A), D72.2 (A), D80.2 (A), D88.2 (A), D96.2 (A), D104.2 (A), D112.2 (A), D120.2 (A), D128.2 (A), D136.2 (A), D144.2 (A), D152.2 (A), D160.2 (A), D168.2 (A), D176.2 (A), D184.2 (A), D192.2 (A), D200.2 (A), D208.2 (A), D216.2 (A), D224.2 (A), D232.2 (A), D240.2 (A), D248.2 (A), D256.2 (A), U1.22 (SW1), U2.22 (SW1)
GND: R13.1, R14.1, R15.1, R16.1, U1.9 (GND), U1.24 (GND), U1.28 (AD), U1.33 (GND), U2.9 (GND), U2.24 (GND), U2.33 (GND), U3.9 (GND), U3.24 (GND), U3.33 (GND), U4.9 (GND), U4.24 (GND), U4.33 (GND); also elsewhere on the board
unnamed: R13.2, U1.25 (ISET)
unnamed: R14.2, U2.25 (ISET)
unnamed: R15.2, U3.25 (ISET)
unnamed: R16.2, U4.25 (ISET)
SCL: U1.27 (SCL), U2.27 (SCL), U2.28 (AD), U3.27 (SCL), U4.27 (SCL); also elsewhere on the board
SDA: U1.26 (SDA), U2.26 (SDA), U3.26 (SDA), U3.28 (AD), U4.26 (SDA); also elsewhere on the board
~LED_SHDN: U1.29 (~SDB), U2.29 (~SDB), U3.29 (~SDB), U4.29 (~SDB); also elsewhere on the board

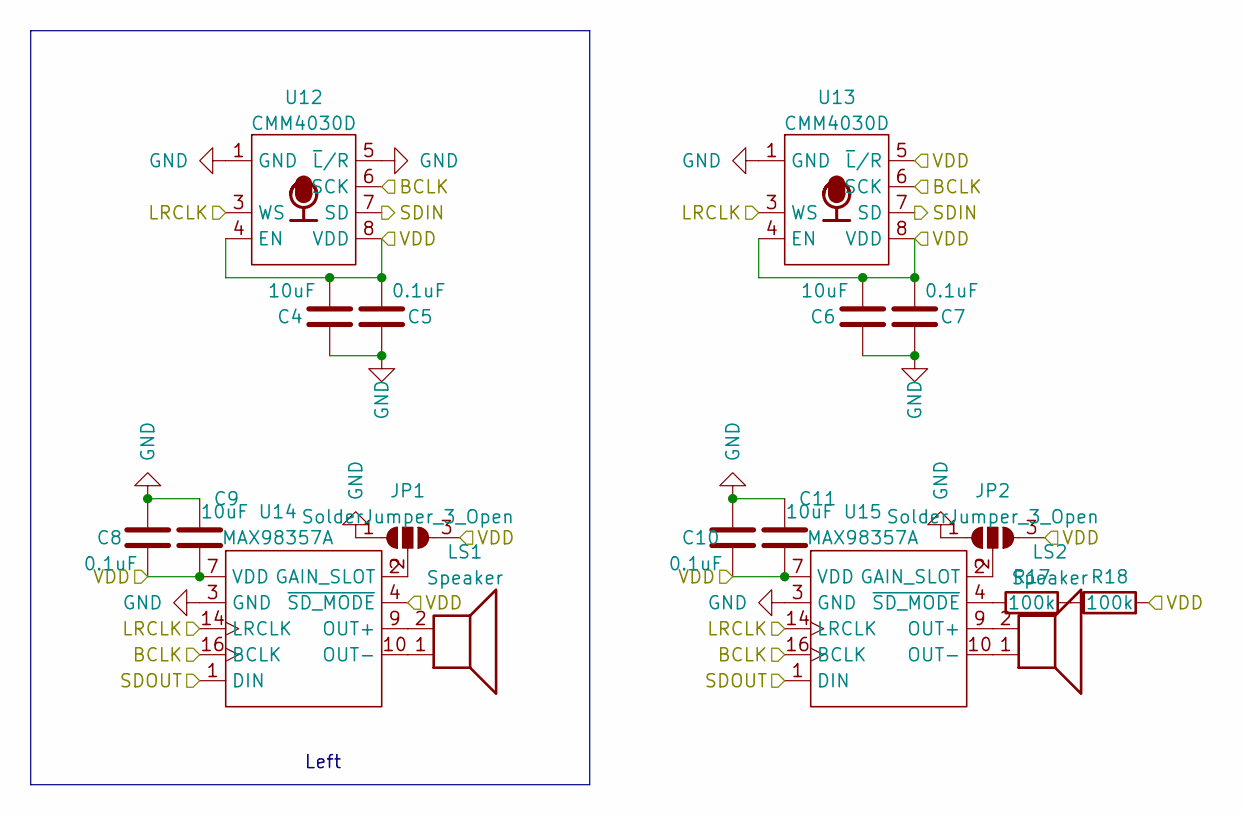
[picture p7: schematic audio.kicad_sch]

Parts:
C4, C6, C9, C11: 10uF; C_0603_1608Metric
C5, C7, C8, C10: 0.1uF; C_0603_1608Metric
JP1, JP2: SolderJumper_3_Open; SolderJumper-3_P1.3mm_Open_RoundedPad1.0x1.5mm
LS1, LS2: Speaker; CMS1609
R17, R18: 100k; R_0603_1608Metric
U12, U13: CMM4030D; CMM4030D_hand_solder
U14, U15: MAX98357A; QFN-16-1EP_3x3mm_P0.5mm_EP1.45x1.45mm

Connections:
+3V3: C4.2, C5.2, C6.2, C7.2, C8.2, C9.2, C10.2, C11.2, JP1.3 (B), JP2.3 (B), R18.2, U12.4 (EN), U12.8 (VDD), U13.4 (EN), U13.5 (~L/R), U13.8 (VDD), U14.4 (~SD_MODE), U14.7 (VDD), U14.8 (VDD), U15.7 (VDD), U15.8 (VDD); also elsewhere on the board
BCLK: U12.6 (SCK), U13.6 (SCK), U14.16 (BCLK), U15.16 (BCLK); also elsewhere on the board
GND: C4.1, C5.1, C6.1, C7.1, C8.1, C9.1, C10.1, C11.1, JP1.1 (A), JP2.1 (A), U12.1 (GND), U12.5 (~L/R), U13.1 (GND), U14.3 (GND), U14.11 (GND), U14.15 (GND), U14.17 (GND), U15.3 (GND), U15.11 (GND), U15.15 (GND), U15.17 (GND); also elsewhere on the board
LRCLK: U12.3 (WS), U13.3 (WS), U14.14 (LRCLK), U15.14 (LRCLK); also elsewhere on the board
unnamed: JP1.2 (C), U14.2 (GAIN_SLOT)
unnamed: JP2.2 (C), U15.2 (GAIN_SLOT)
unnamed: LS1.1, U14.10 (OUT-)
unnamed: LS1.2, U14.9 (OUT+)
unnamed: LS2.1, U15.10 (OUT-)
unnamed: LS2.2, U15.9 (OUT+)
unnamed: R17.1, U15.4 (~SD_MODE)
unnamed: R17.2, R18.1
SDIN: U12.7 (SD), U13.7 (SD); also elsewhere on the board
SDOUT: U14.1 (DIN), U15.1 (DIN); also elsewhere on the board

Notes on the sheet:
Left

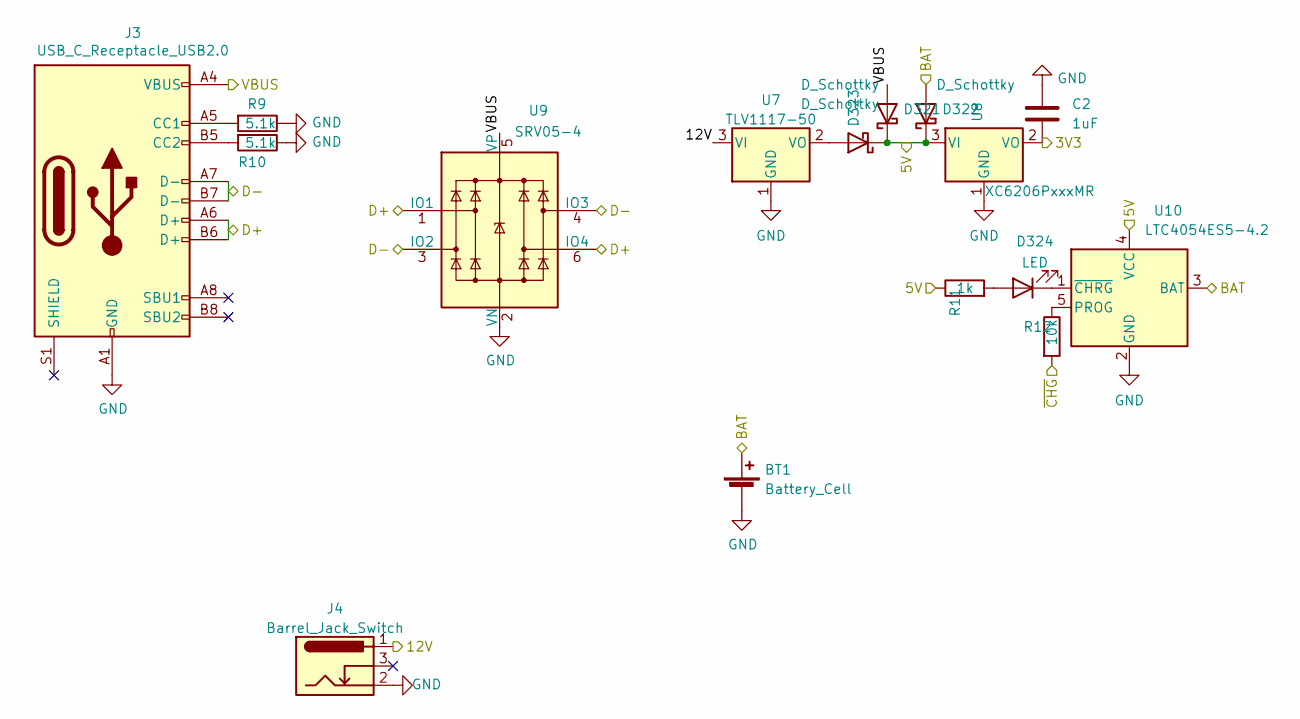
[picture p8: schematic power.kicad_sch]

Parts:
BT1: Battery_Cell; JST_PH_S2B-PH-SM4-TB_1x02-1MP_P2.00mm_Horizontal
C2: 1uF; C_0603_1608Metric
D321, D322, D323: D_Schottky; D_SOD-123
D324: LED; D_0805_2012Metric
J3: USB_C_Receptacle_USB2.0; USB_C_Receptacle_HRO_TYPE-C-31-M-12
J4: Barrel_Jack_Switch; BarrelJack_CUI_PJ-102AH_Horizontal
R9, R10: 5.1k; R_0603_1608Metric
R11: 1k; R_0603_1608Metric
R12: 10k; R_0603_1608Metric
U7: TLV1117-50; SOT-223
U8: XC6206PxxxMR; SOT-23
U9: SRV05-4; SOT-23-6
U10: LTC4054ES5-4.2; TSOT-23-5

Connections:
+3V3: C2.2, U8.2 (VO); also elsewhere on the board
+5V: D321.1 (K), D322.1 (K), D323.1 (K), R11.1, U8.3 (VI), U10.4 (VCC); also elsewhere on the board
+12V: J4.1, U7.3 (VI); also elsewhere on the board
+BATT: BT1.1 (+), D322.2 (A), U10.3 (BAT); also elsewhere on the board
D+: J3.A6 (D+), J3.B6 (D+), U9.1 (IO1), U9.6 (IO4); also elsewhere on the board
D-: J3.A7 (D-), J3.B7 (D-), U9.3 (IO2), U9.4 (IO3); also elsewhere on the board
GND: BT1.2 (-), C2.1, J3.A1 (GND), J3.A12 (GND), J3.B1 (GND), J3.B12 (GND), J4.2, R9.1, R10.1, U7.1 (GND), U8.1 (GND), U9.2 (VN), U10.2 (GND); also elsewhere on the board
unnamed: D323.2 (A), U7.2 (VO)
unnamed: D324.1 (K), U10.1 (~CHRG)
unnamed: D324.2 (A), R11.2
unnamed: J3.A5 (CC1), R9.2
unnamed: J3.B5 (CC2), R10.2
unnamed: R12.1, U10.5 (PROG)
VBUS: D321.2 (A), J3.A4 (VBUS), J3.A9 (VBUS), J3.B4 (VBUS), J3.B9 (VBUS), U9.5 (VP); also elsewhere on the board
~CHG: R12.2; also elsewhere on the board

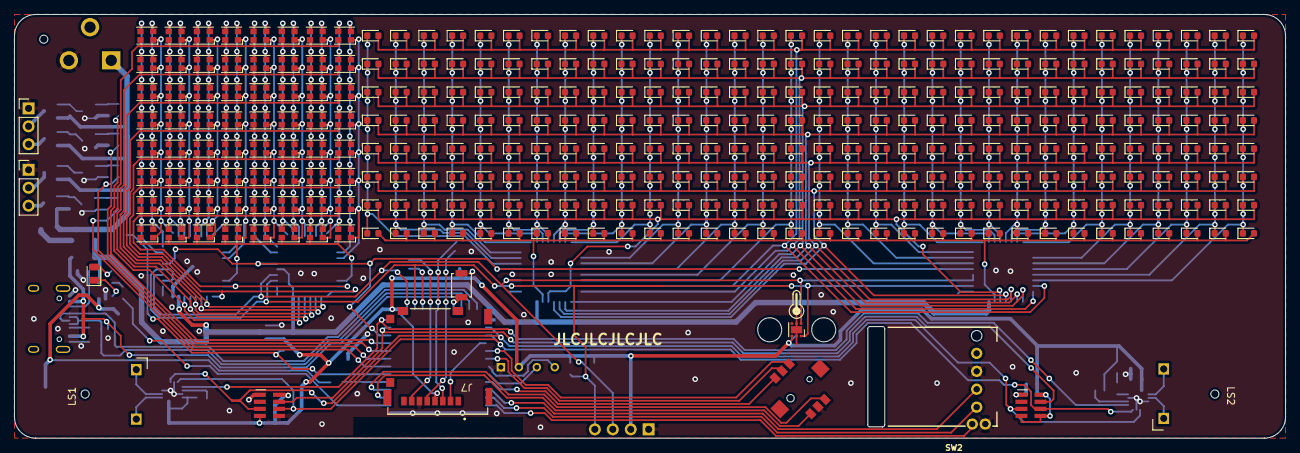
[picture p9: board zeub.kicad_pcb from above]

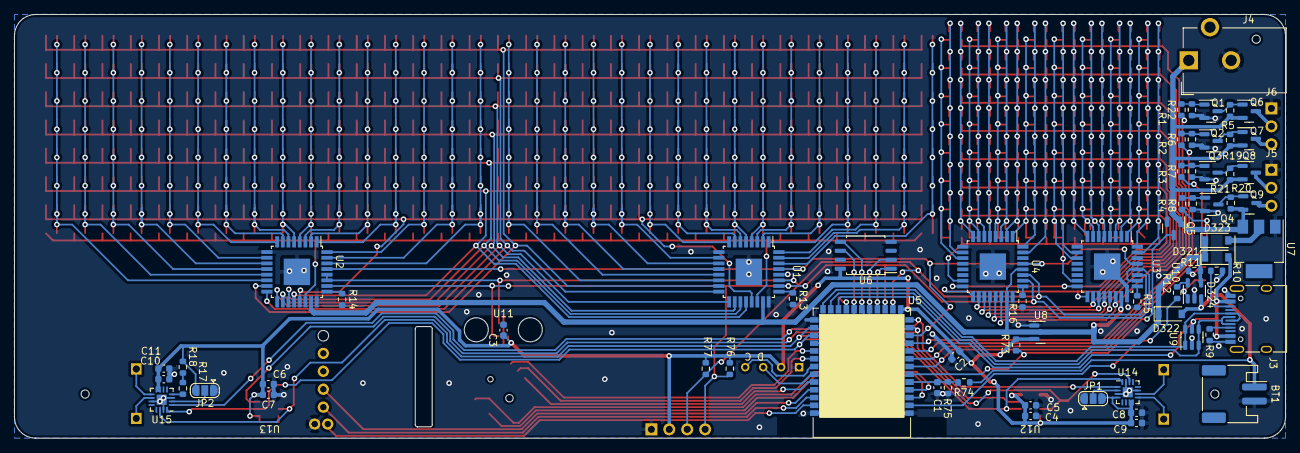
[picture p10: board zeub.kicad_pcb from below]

Board: 2 copper layers, 180.0 x 60.0 mm, 401 parts (68 on the bottom side), 140 nets.

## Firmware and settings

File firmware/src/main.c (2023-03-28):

#include <zephyr/device.h>
#include <zephyr/kernel.h>
#include <zephyr/drivers/gpio.h>
#include <zephyr/drivers/kscan.h>
#include <zephyr/drivers/sensor.h>

#include <zephyr/logging/log.h>
LOG_MODULE_REGISTER(zeub, CONFIG_ZEUB_LOG_LEVEL);

#include "disp.h"
#include "zeub_time.h"
#include "strip.h"

static const struct device *buttons = DEVICE_DT_GET(DT_NODELABEL(buttons)),
             *roller = DEVICE_DT_GET(DT_NODELABEL(roller));

static void minute_timer_sync_work_cb(struct k_work *work);
static void minute_timer_cb();
static K_WORK_DELAYABLE_DEFINE(minute_timer_sync_work, minute_timer_sync_work_cb);
static K_TIMER_DEFINE(minute_timer, minute_timer_cb, NULL);

enum button {
    ENC_PUSH = 0,
    SEL_UP,
    SEL_DOWN,
    SEL_LEFT,
    SEL_RIGHT,
    SEL_PUSH,
    ROLL_UP,
    ROLL_DOWN,
};

static void handle_button(const struct device *dev, enum button button, bool pressed) {
    static uint8_t channel = 1;
    int ret;
    if (pressed) {
        switch (button) {
        case SEL_PUSH:
            break;
        case ENC_PUSH:
            channel = !channel;
            break;
        case ROLL_UP:
            change_bright(2 + channel, 1);
            break;
        case ROLL_DOWN:
            change_bright(2 + channel, -1);
            break;
        default:
            break;
        }
    }
}

static inline void buttons_cb(const struct device *dev, uint32_t row, uint32_t col, bool pressed) {
    LOG_DBG("buttons %u %d", col, pressed);
    handle_button(dev, col, pressed);
}

static inline void roller_cb(const struct device *dev, uint32_t row, uint32_t col, bool pressed) {
    /* LOG_DBG("roller %u %d", col, pressed); */
    handle_button(dev, col + ROLL_UP, pressed);
}

void zeub_handle_time(const struct time_state *time) {
    const uint32_t rem_ms = (60 - time->time.tm_sec) * 1000 - time->frag * 1000 / 256;
    LOG_WRN("rem ms %u", rem_ms);
    disp_update_time(time, true);
    k_work_schedule(&minute_timer_sync_work, K_MSEC(rem_ms));
}

static void minute_timer_sync_work_cb(struct k_work *work) {
    int32_t skew_ms = k_timer_remaining_get(&minute_timer);
    if (skew_ms > 30000) {
        skew_ms = skew_ms - 60000;
    }
    LOG_INF("skew ms %d", skew_ms);
    k_timer_start(&minute_timer, K_NO_WAIT, K_MINUTES(1));
}

static void minute_timer_cb() {
    struct time_state now;
    int ret = time_get_unix_time(&now);
    if (ret < 0) {
        LOG_ERR("get time %d", ret);
        return;
    }
    disp_update_time(&now, false);
    strip_handle_time(&now);
}

int main() {
    int ret;

    kscan_config(roller, roller_cb);
    kscan_enable_callback(roller);
    kscan_config(buttons, buttons_cb);
    kscan_enable_callback(buttons);

    return 0;
}

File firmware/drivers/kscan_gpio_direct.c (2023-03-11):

/*
 * Copyright (c) 2020 The ZMK Contributors
 *
 * SPDX-License-Identifier: MIT
 */

#define DT_DRV_COMPAT zeub_kscan_gpio_direct

#include <zephyr/device.h>
#include <zephyr/kernel.h>
#include <zephyr/drivers/kscan.h>
#include <zephyr/drivers/gpio.h>
#include <zephyr/logging/log.h>

LOG_MODULE_REGISTER(zeub_kscan, CONFIG_ZEUB_KSCAN_LOG_LEVEL);

#if DT_HAS_COMPAT_STATUS_OKAY(DT_DRV_COMPAT)

union work_reference {
    struct k_work_delayable delayed;
    struct k_work direct;
};

struct kscan_gpio_config {
    uint8_t num_of_inputs;
    uint8_t debounce_period;
    struct gpio_dt_spec input_specs[];
};

struct kscan_gpio_data {
    kscan_callback_t callback;
    union work_reference work;
    const struct device *dev;
    uint32_t pin_state;
};

static void kscan_gpio_direct_queue_read(union work_reference *work, uint8_t debounce_period) {
    if (debounce_period > 0) {
        k_work_reschedule(&work->delayed, K_MSEC(debounce_period));
    } else {
        k_work_submit(&work->direct);
    }
}

struct kscan_gpio_irq_callback {
    const struct device *dev;
    union work_reference *work;
    uint8_t debounce_period;
    struct gpio_callback callback;
};

static int kscan_gpio_config_interrupts(const struct device *dev, gpio_flags_t flags) {
    const struct kscan_gpio_config *cfg = dev->config;
    const struct gpio_dt_spec *specs = cfg->input_specs;

    for (int i = 0; i < cfg->num_of_inputs; i++) {
        int err = gpio_pin_interrupt_configure_dt(&specs[i], flags);

        if (err) {
            LOG_ERR("Unable to enable direct GPIO interrupt");
            return err;
        }
    }

    return 0;
}

static int kscan_gpio_direct_enable(const struct device *dev) {
    return kscan_gpio_config_interrupts(dev, GPIO_INT_LEVEL_ACTIVE);
}
static int kscan_gpio_direct_disable(const struct device *dev) {
    return kscan_gpio_config_interrupts(dev, GPIO_INT_DISABLE);
}

static void kscan_gpio_irq_callback_handler(const struct device *dev, struct gpio_callback *cb,
                                            gpio_port_pins_t pin) {
    struct kscan_gpio_irq_callback *data =
        CONTAINER_OF(cb, struct kscan_gpio_irq_callback, callback);

    kscan_gpio_direct_disable(data->dev);
    kscan_gpio_direct_queue_read(data->work, data->debounce_period);
}

static int kscan_gpio_direct_configure(const struct device *dev, kscan_callback_t callback) {
    struct kscan_gpio_data *data = dev->data;
    if (!callback) {
        return -EINVAL;
    }
    data->callback = callback;
    return 0;
}

static int kscan_gpio_read(const struct device *dev) {
    struct kscan_gpio_data *data = dev->data;
    const struct kscan_gpio_config *cfg = dev->config;
    uint32_t read_state = data->pin_state;
    bool submit_follow_up_read = false;
    for (int i = 0; i < cfg->num_of_inputs; i++) {
        const struct gpio_dt_spec *pin_spec = &cfg->input_specs[i];
        WRITE_BIT(read_state, i, gpio_pin_get_dt(pin_spec) > 0);
    }
    for (int i = 0; i < cfg->num_of_inputs; i++) {
        bool prev_pressed = BIT(i) & data->pin_state;
        bool pressed = (BIT(i) & read_state) != 0;
        submit_follow_up_read = (submit_follow_up_read || pressed);
        if (pressed != prev_pressed) {
            LOG_DBG("Sending event at %d,%d state %s", 0, i, (pressed ? "on" : "off"));
            WRITE_BIT(data->pin_state, i, pressed);
            data->callback(dev, 0, i, pressed);
        }
    }

    if (submit_follow_up_read) {
        kscan_gpio_direct_queue_read(&data->work, cfg->debounce_period);
    } else {
        kscan_gpio_direct_enable(dev);
    }

    return 0;
}

static void kscan_gpio_work_handler(struct k_work *work) {
    struct kscan_gpio_data *data = CONTAINER_OF(work, struct kscan_gpio_data, work);
    kscan_gpio_read(data->dev);
}

static const struct kscan_driver_api gpio_driver_api = {
    .config = kscan_gpio_direct_configure,
    .enable_callback = kscan_gpio_direct_enable,
    .disable_callback = kscan_gpio_direct_disable,
};

#define KSCAN_DIRECT_INPUT_ITEM(i, n) GPIO_DT_SPEC_GET_BY_IDX(DT_DRV_INST(n), input_gpios, i),

#define INST_INPUT_LEN(n) DT_INST_PROP_LEN(n, input_gpios)
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

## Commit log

2022-03-28 routed whites
    [led.kicad_sch, power.kicad_sch, zeub.kicad_pcb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]
2022-03-28 routed RGB
    [zeub.kicad_pcb]
2022-03-28 routed matrix + PWM driver
    [led.kicad_sch, power.kicad_sch, zeub.kicad_pcb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]
2022-03-28 routed PMU
    [led.kicad_sch, power.kicad_sch, zeub.kicad_pcb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]
2022-03-28 routed PMU + rull RGB
    [led.kicad_sch, zeub.kicad_pcb, zeub.kicad_sch]
2022-03-28 routed all LED + PMU
    [power.kicad_sch, zeub.kicad_pcb, zeub.kicad_sch]
2022-03-28 rid of LED driver resistors
    [led.kicad_sch, power.kicad_sch, zeub.kicad_pcb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]
2022-03-28 Added audio stuff; rerouted for prep
    [audio.kicad_sch, zeub.kicad_pcb, zeub.kicad_sch]
2022-03-28 fully routed
    [audio.kicad_sch, zeub.kicad_pcb, zeub.kicad_sch]
2022-03-28 first version
    [led.kicad_sch, zeub-bom.csv, zeub.kicad_pcb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]
2022-05-16 pcb: move into own directory
    [audio.kicad_sch, led.kicad_sch, power.kicad_sch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]
2022-05-31 3D models
    [zeub.kicad_pcb]
2023-03-13 stamp ground vias; ERC
    [audio.kicad_sch, led.kicad_sch, power.kicad_sch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]
2023-03-16 v2 fabbed
    [led.kicad_sch, zeub-bom.csv, zeub.kicad_sch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]
2023-03-26 add is31fl3741 driver
    from https://github.com/zmkfirmware/zmk/pull/866
2023-03-28 firmware: zeub v2: simple clock icon and time on led matrix
